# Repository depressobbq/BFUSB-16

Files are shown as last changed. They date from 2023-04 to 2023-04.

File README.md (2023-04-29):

# BFUSB-16
its a Big effin USB hub, based on off the shelf parts.

The goal here is to have something with easy to source parts, that asre simultaniously as easy to solder by hand as possible. I went with good ol barrel caps, and single stacked usbs. Also I went with crystals at each of the hub chips, despite them being able to run without one, just due to no trusting it to actually do so. the hope here being that with nice big beefy caps and crystals on each hub chip, this thing ought to be stable even fully populated.
If it works as intended, it should be great for people like me who need a million USB's hooked to their PC for sim racing, but it would also be cool to see if it would work as a 16 USB RAID0 (if my numbers are correct your average flashdrive * 16 is the full usb 2 bandwidth)
Any comments / questions, leave them in the issues, and if you want to help improve the design make a pull request. Im usually not far from a keyboard. This PCB should be good to go with either JLCPCB ( my favorite) or PCBWay.
BFUSB-16_Front
BFUSB-16_Back

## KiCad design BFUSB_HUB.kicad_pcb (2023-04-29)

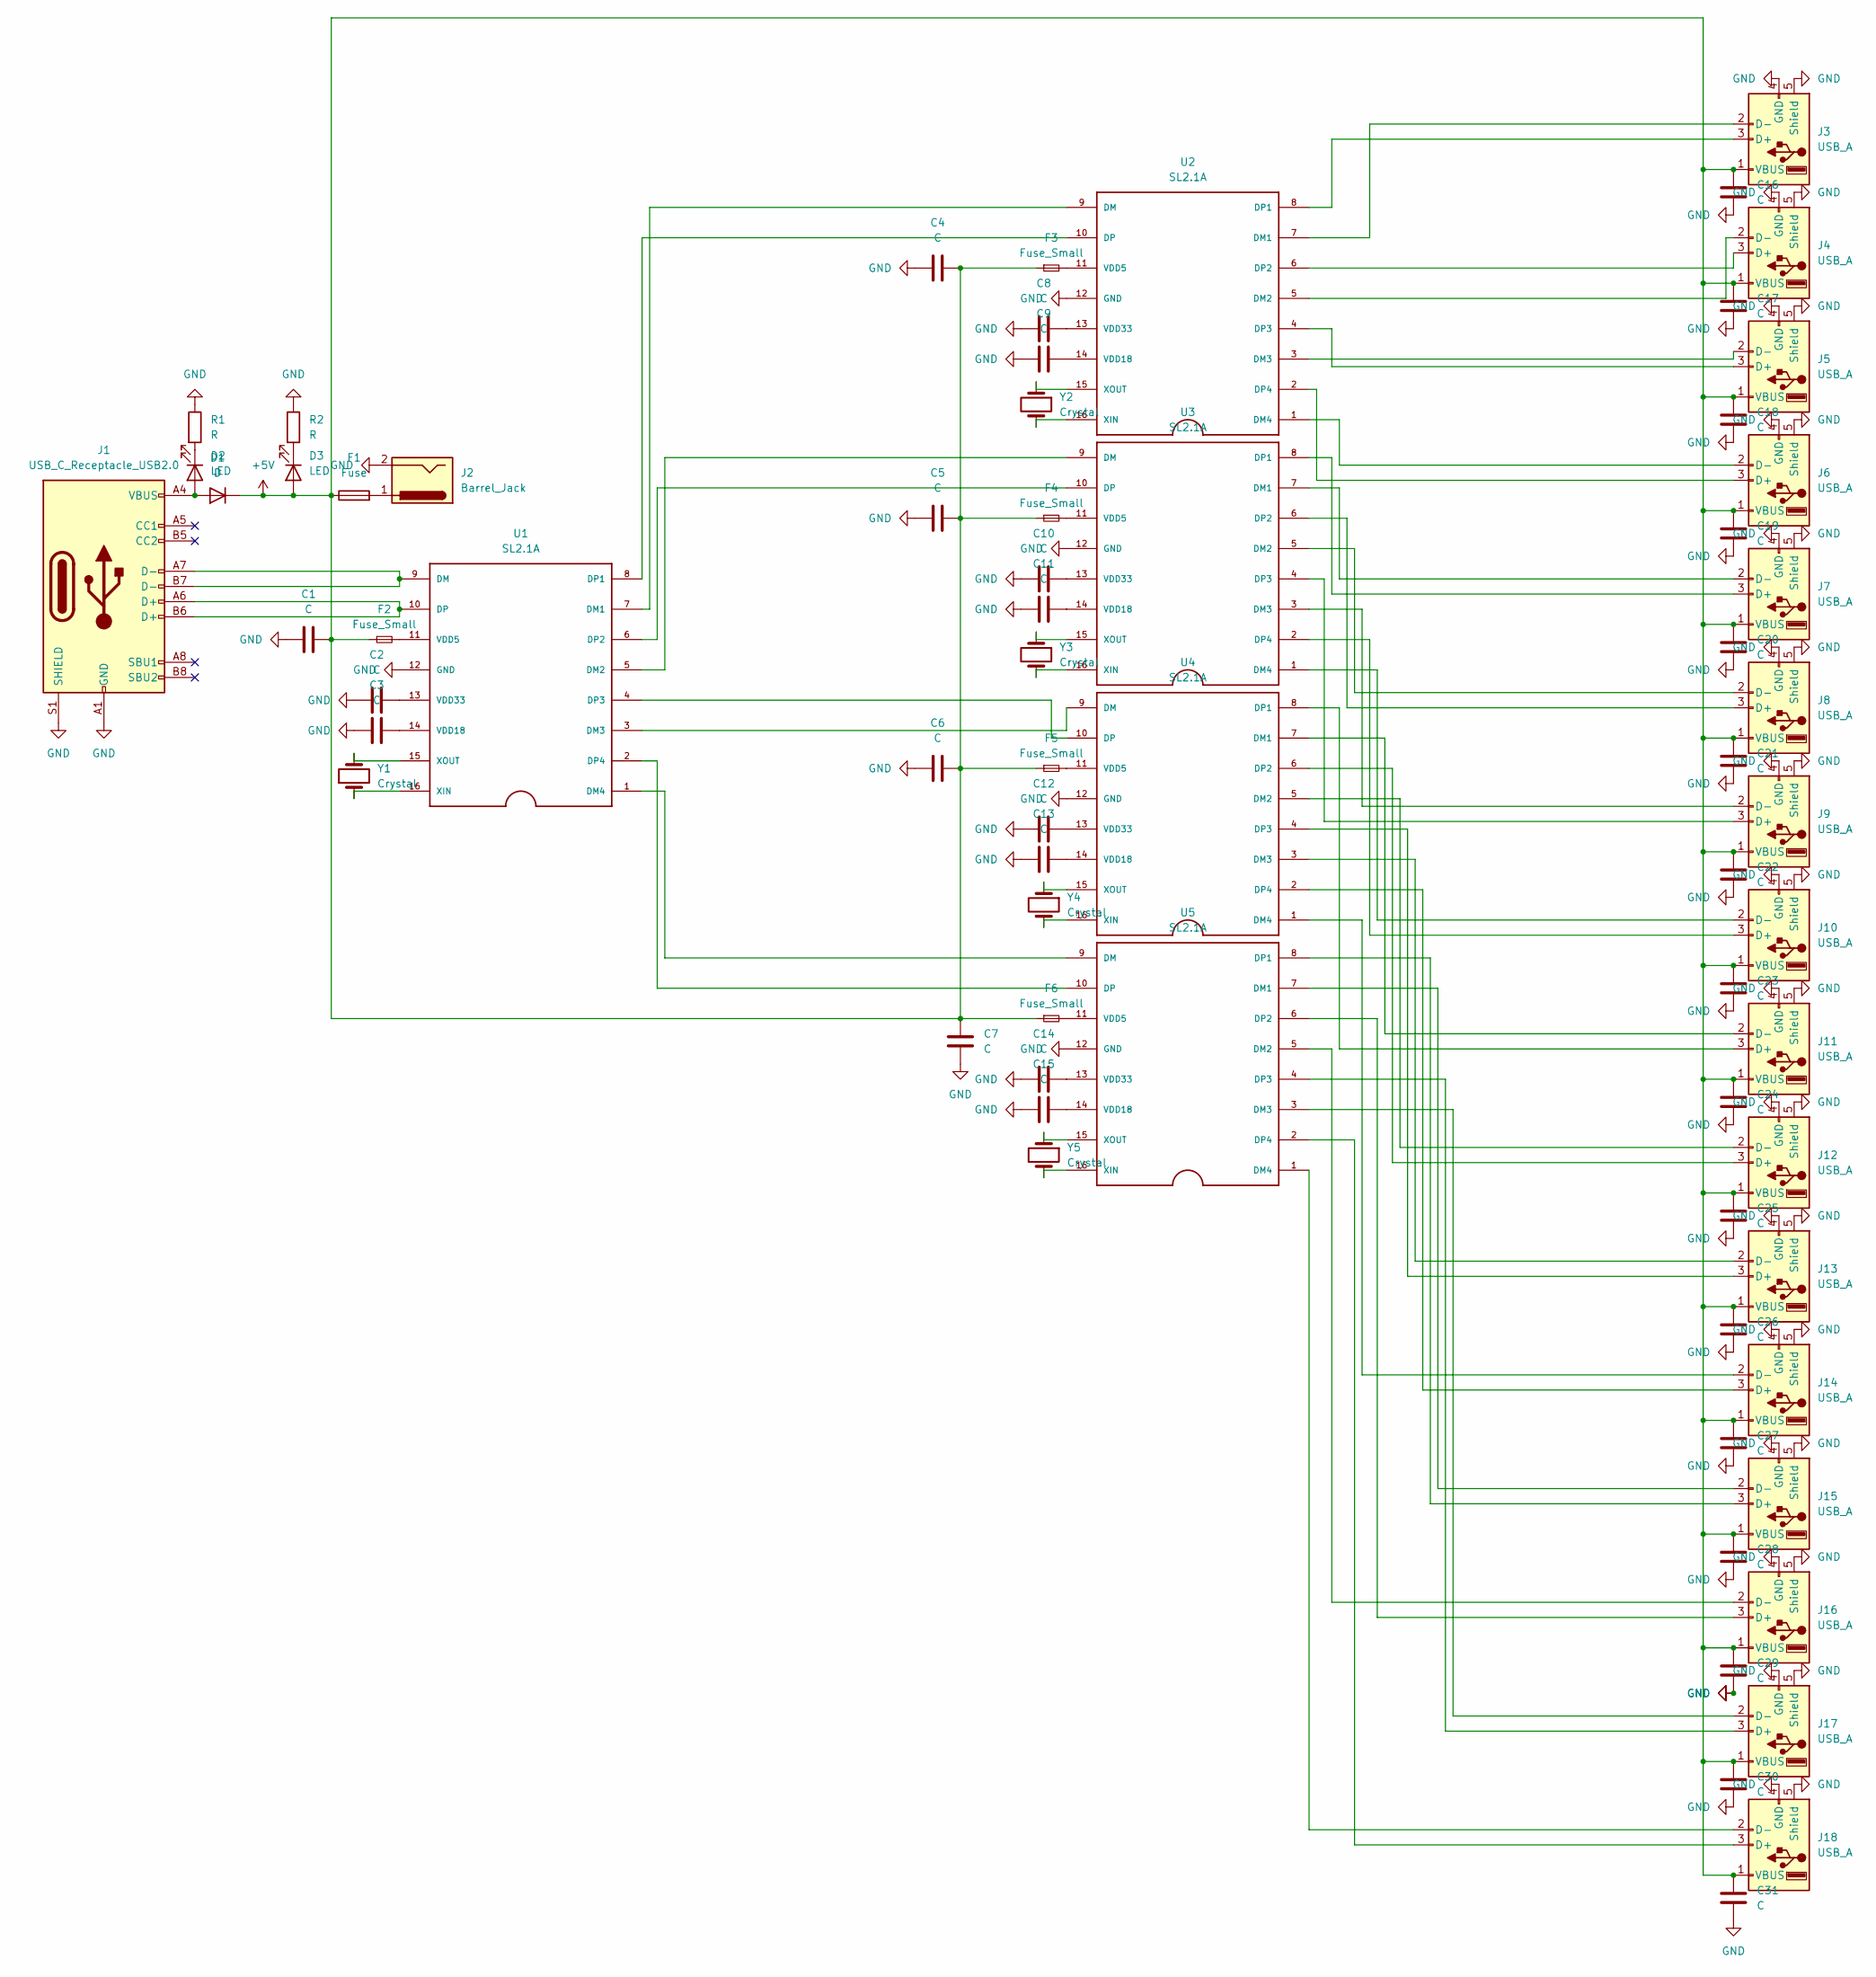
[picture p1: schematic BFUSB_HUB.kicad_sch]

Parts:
C1, C2, C3, C4, C5, C6, C7, C8, C9, C10, C11, C12, C13, C14, C15, C16, C17, C18, C19, C20, C21, C22, C23, C24, C25, C26, C27, C28, C29, C30, C31: C; C_Radial_D10.0mm_H12.5mm_P5.00mm
D1: D; D_DO-41_SOD81_P10.16mm_Horizontal
D2, D3: LED; LED_D3.0mm
F1: Fuse; Fuseholder_Cylinder-5x20mm_Stelvio-Kontek_PTF78_Horizontal_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
F2, F3, F4, F5, F6: Fuse_Small; Fuse_2920_7451Metric_Pad2.10x5.45mm_HandSolder
J1: USB_C_Receptacle_USB2.0; USB_C_Receptacle_HRO_TYPE-C-31-M-12
J2: Barrel_Jack; BarrelJack_CUI_PJ-063AH_Horizontal
J3, J4, J5, J6, J7, J8, J9, J10, J11, J12, J13, J14, J15, J16, J17, J18: USB_A; USB_A_Stewart_SS-52100-001_Horizontal
R1, R2: R; R_Axial_DIN0204_L3.6mm_D1.6mm_P1.90mm_Vertical
U1, U2, U3, U4, U5: SL2.1A; SO16
Y1, Y2, Y3, Y4, Y5: Crystal; Crystal_HC49-U_Vertical

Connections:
+5V: C1.2, C4.2, C5.2, C6.2, C7.2, C16.1, C17.1, C18.1, C19.1, C20.1, C21.1, C22.1, C23.1, C24.1, C25.1, C26.1, C27.1, C28.1, C29.1, C30.1, C31.1, D1.1 (K), D3.2 (A), F1.1, F2.1, F3.1, F4.1, F5.1, F6.1, J3.1 (VBUS), J4.1 (VBUS), J5.1 (VBUS), J6.1 (VBUS), J7.1 (VBUS), J8.1 (VBUS), J9.1 (VBUS), J10.1 (VBUS), J11.1 (VBUS), J12.1 (VBUS), J13.1 (VBUS), J14.1 (VBUS), J15.1 (VBUS), J16.1 (VBUS), J17.1 (VBUS), J18.1 (VBUS)
GND: C1.1, C2.1, C3.1, C4.1, C5.1, C6.1, C7.1, C8.1, C9.1, C10.1, C11.1, C12.1, C13.1, C14.1, C15.1, C16.2, C17.2, C18.2, C19.2, C20.2, C21.2, C22.2, C23.2, C24.2, C25.2, C26.2, C27.2, C28.2, C29.2, C30.2, C31.2, J1.A1 (GND), J1.A12 (GND), J1.B1 (GND), J1.B12 (GND), J1.S1 (SHIELD), J2.2, J3.4 (GND), J3.5 (Shield), J4.4 (GND), J4.5 (Shield), J5.4 (GND), J5.5 (Shield), J6.4 (GND), J6.5 (Shield), J7.4 (GND), J7.5 (Shield), J8.4 (GND), J8.5 (Shield), J9.4 (GND), J9.5 (Shield), J10.4 (GND), J10.5 (Shield), J11.4 (GND), J11.5 (Shield), J12.4 (GND), J12.5 (Shield), J13.4 (GND), J13.5 (Shield), J14.4 (GND), J14.5 (Shield), J15.4 (GND), J15.5 (Shield), J16.4 (GND), J16.5 (Shield), J17.4 (GND), J17.5 (Shield), J18.4 (GND), J18.5 (Shield), R1.1, R2.1, U1.12 (GND), U2.12 (GND), U3.12 (GND), U4.12 (GND), U5.12 (GND)
unnamed: C2.2, U1.13 (VDD33)
unnamed: C3.2, U1.14 (VDD18)
unnamed: C8.2, U2.13 (VDD33)
unnamed: C9.2, U2.14 (VDD18)
unnamed: C10.2, U3.13 (VDD33)
unnamed: C11.2, U3.14 (VDD18)
unnamed: C12.2, U4.13 (VDD33)
unnamed: C13.2, U4.14 (VDD18)
unnamed: C14.2, U5.13 (VDD33)
unnamed: C15.2, U5.14 (VDD18)
unnamed: D1.2 (A), D2.2 (A), J1.A4 (VBUS), J1.A9 (VBUS), J1.B4 (VBUS), J1.B9 (VBUS)
unnamed: D2.1 (K), R1.2
unnamed: D3.1 (K), R2.2
unnamed: F1.2, J2.1
unnamed: F2.2, U1.11 (VDD5)
unnamed: F3.2, U2.11 (VDD5)
unnamed: F4.2, U3.11 (VDD5)
unnamed: F5.2, U4.11 (VDD5)
unnamed: F6.2, U5.11 (VDD5)
unnamed: J1.A6 (D+), J1.B6 (D+), U1.10 (DP)
unnamed: J1.A7 (D-), J1.B7 (D-), U1.9 (DM)
unnamed: J3.2 (D-), U2.7 (DM1)
unnamed: J3.3 (D+), U2.8 (DP1)
unnamed: J4.2 (D-), U2.5 (DM2)
unnamed: J4.3 (D+), U2.6 (DP2)
unnamed: J5.2 (D-), U2.3 (DM3)
unnamed: J5.3 (D+), U2.4 (DP3)
unnamed: J6.2 (D-), U2.1 (DM4)
unnamed: J6.3 (D+), U2.2 (DP4)
unnamed: J7.2 (D-), U3.7 (DM1)
unnamed: J7.3 (D+), U3.8 (DP1)
unnamed: J8.2 (D-), U3.5 (DM2)
unnamed: J8.3 (D+), U3.6 (DP2)
unnamed: J9.2 (D-), U3.3 (DM3)
unnamed: J9.3 (D+), U3.4 (DP3)
unnamed: J10.2 (D-), U3.1 (DM4)
unnamed: J10.3 (D+), U3.2 (DP4)
unnamed: J11.2 (D-), U4.7 (DM1)
unnamed: J11.3 (D+), U4.8 (DP1)
unnamed: J12.2 (D-), U4.5 (DM2)
unnamed: J12.3 (D+), U4.6 (DP2)
unnamed: J13.2 (D-), U4.3 (DM3)
unnamed: J13.3 (D+), U4.4 (DP3)
unnamed: J14.2 (D-), U4.1 (DM4)
unnamed: J14.3 (D+), U4.2 (DP4)
unnamed: J15.2 (D-), U5.7 (DM1)
unnamed: J15.3 (D+), U5.8 (DP1)
unnamed: J16.2 (D-), U5.5 (DM2)
unnamed: J16.3 (D+), U5.6 (DP2)
unnamed: J17.2 (D-), U5.3 (DM3)
unnamed: J17.3 (D+), U5.4 (DP3)
unnamed: J18.2 (D-), U5.1 (DM4)
unnamed: J18.3 (D+), U5.2 (DP4)
unnamed: U1.1 (DM4), U5.9 (DM)
unnamed: U1.2 (DP4), U5.10 (DP)
unnamed: U1.3 (DM3), U4.9 (DM)
unnamed: U1.4 (DP3), U4.10 (DP)
unnamed: U1.5 (DM2), U3.9 (DM)
unnamed: U1.6 (DP2), U3.10 (DP)
unnamed: U1.7 (DM1), U2.9 (DM)
unnamed: U1.8 (DP1), U2.10 (DP)
unnamed: U1.15 (XOUT), Y1.2
unnamed: U1.16 (XIN), Y1.1
unnamed: U2.15 (XOUT), Y2.1
unnamed: U2.16 (XIN), Y2.2
unnamed: U3.15 (XOUT), Y3.1
unnamed: U3.16 (XIN), Y3.2
unnamed: U4.15 (XOUT), Y4.1
unnamed: U4.16 (XIN), Y4.2
unnamed: U5.15 (XOUT), Y5.1
unnamed: U5.16 (XIN), Y5.2

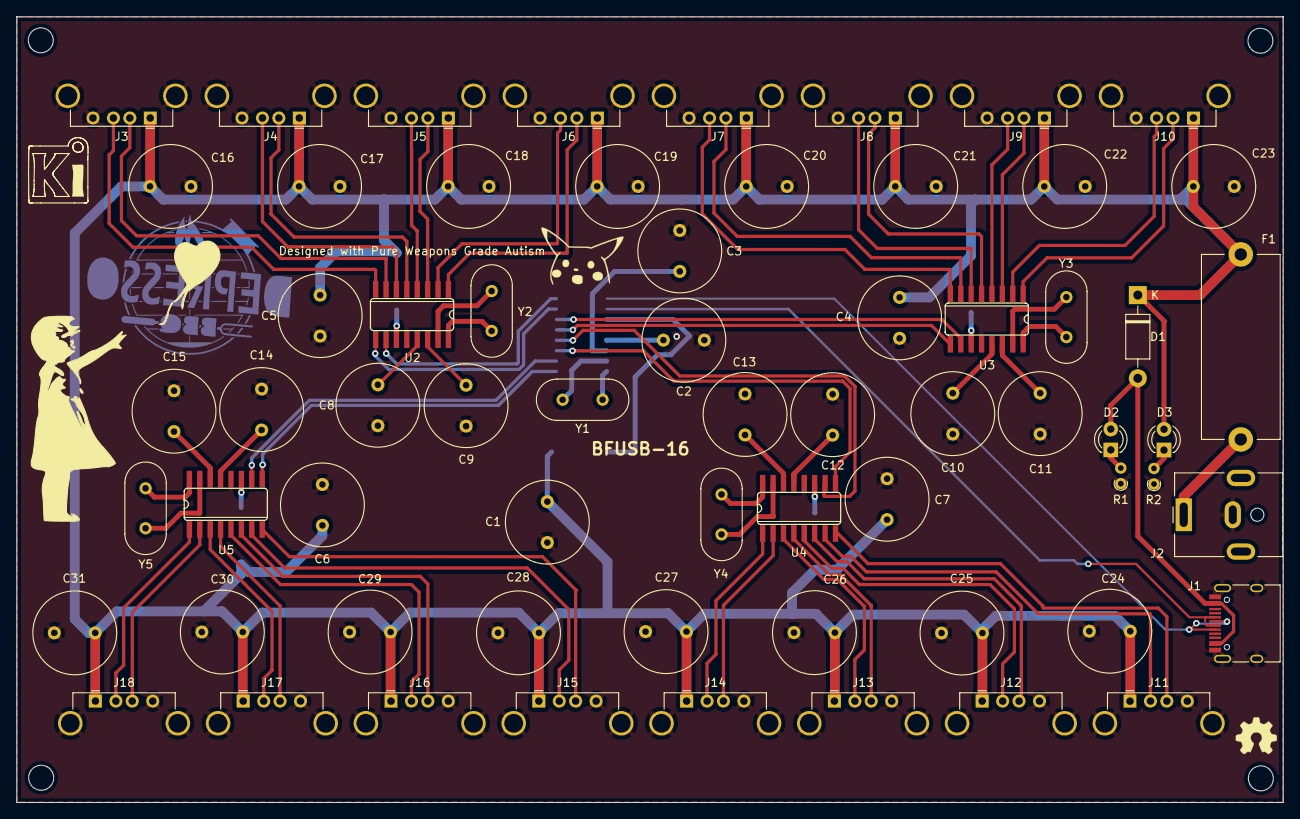
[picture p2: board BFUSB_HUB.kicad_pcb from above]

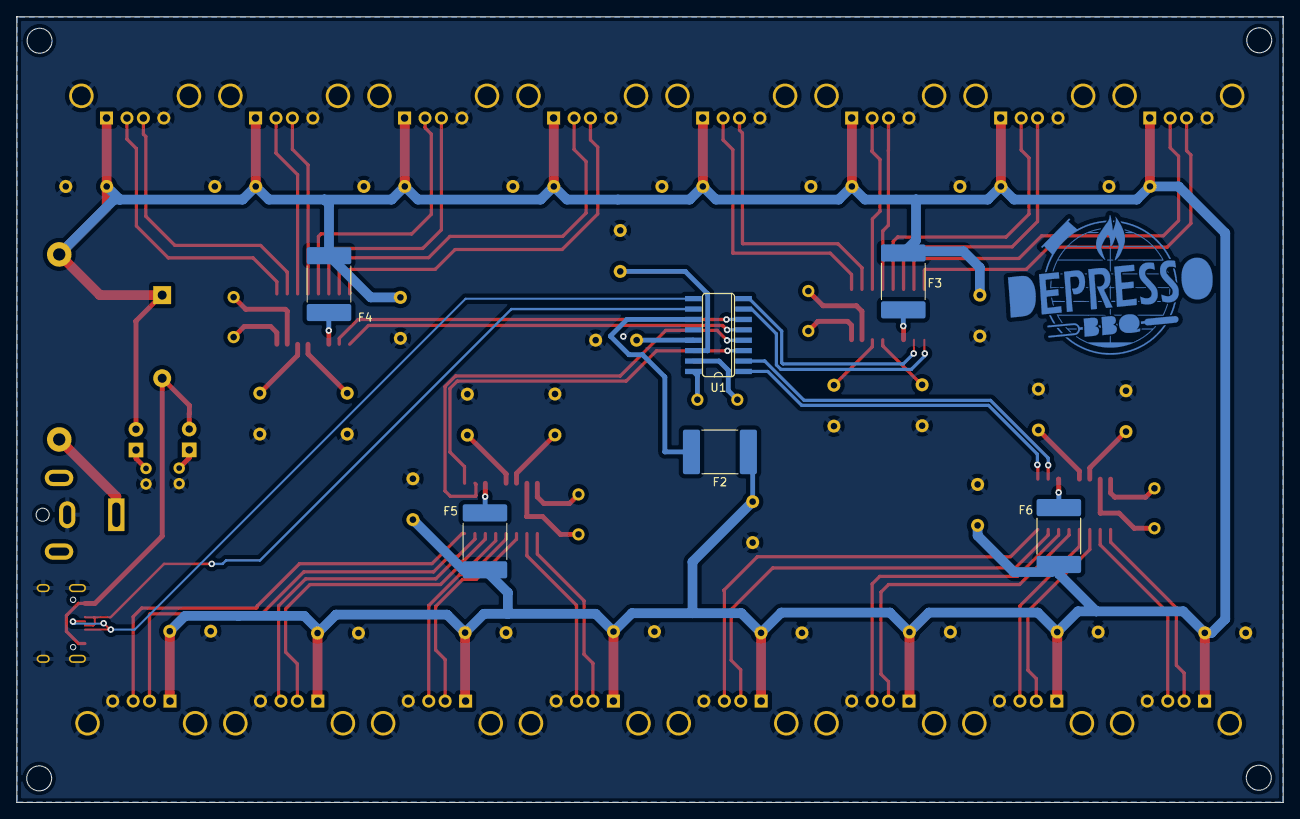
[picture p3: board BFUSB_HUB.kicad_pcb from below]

Board: 2 copper layers, 154.7 x 96.0 mm, 70 parts (6 on the bottom side), 73 nets.

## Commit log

2023-04-29 Update README.md
    added pictures of board
2023-04-29 added silksreen model number to board
    [BFUSB_HUB-B_Adhesive.gbr, BFUSB_HUB-B_Courtyard.gbr, BFUSB_HUB-B_Cu.gbr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]
